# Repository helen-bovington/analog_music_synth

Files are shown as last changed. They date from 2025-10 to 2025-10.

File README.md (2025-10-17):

# EE Senior Capstone - Surface Electromyogram-Controlled (sEMG) Analog Audio Synthesizer
## Capstone Members - Helen Bovington, Anya Trumbach, Daryl Choo, Kayla Montgomery
## Date Completed : 15 May 2025 

HOW TO RUN THIS CODE

Hardware
- To simulate the hardware circuit, install Cadence Virtuoso. This program allows transistor-level schematic simulation.
- Download the entire folder of Cadence files included in this repository, create a new library in Virtuoso, and use ADE L to execute the simulations.
- Both the fully integrated circuit and individual blocks can be simulated independently.

Software
- To simulate the software, you will need at least three ESP32 chips, one server and two clients.
- Upload the corresponding client and server code to each chip, and follow the directions in the technical documentation.
- Note that fully reproducing the system may be challenging, as it requires integrating both the EMG and 9DOF sensors, and successfully implementing the communication protocol in all the ESP32 chips.

DESCRIPTION OF EACH FILE/FOLDER: 

Cadence_files 

- Contains all Cadence schematic files for download, simulation, or modification. Includes the spiceText and symbol files required to run the analog synthesizer circuits successfully.

PCB_documents

- Contains all the PCB schematic (.SchDoc) and layout (.PcbDoc) files for the analog synthesizer blocks, including CEM3340 VCO, Gilbert Mixer, LIN-EXPO Converter, VCA, MUX, Sustain, and Waveform Reshaper circuits.

schematics_and_waveforms

- Contains screenshots of all the Cadence schematics and resulting simulated waveforms for the analog synthesizer blocks.

video_demos

- [Watch the pitch_volume_demo](https://drive.google.com/file/d/1nATk0rh68sWONzXLJCf0UebWwm36ZEd-/view?usp=drive_link)
- [Watch the waveform_demo](https://drive.google.com/file/d/1uY7D6FP98FlUV1h7C2OQBhmS08Et43su/view?usp=sharing)

analog_synth_block_diagram.png

- A high-level, but complete and accurate, block diagram showing how the various blocks of the analog synthesizer are connected.

analog_synth_poster.pdf

- A project poster summarizing the design, implementation, and results of the analog synthesizer capstone project.

system_block_diagram.png

- A block diagram showing the whole system integration including the 9DOF and sEMG sensors, ESP32 chips, communication protocol, analog circuit, and power amp leading to the speaker.

technical_report.pdf

- A document which organizes and details all aspect of the project. It includes all the communication and ML code, decription of the movement library, detailed descriptions of the analog blocks, and short overview of the PCB fabrication process.

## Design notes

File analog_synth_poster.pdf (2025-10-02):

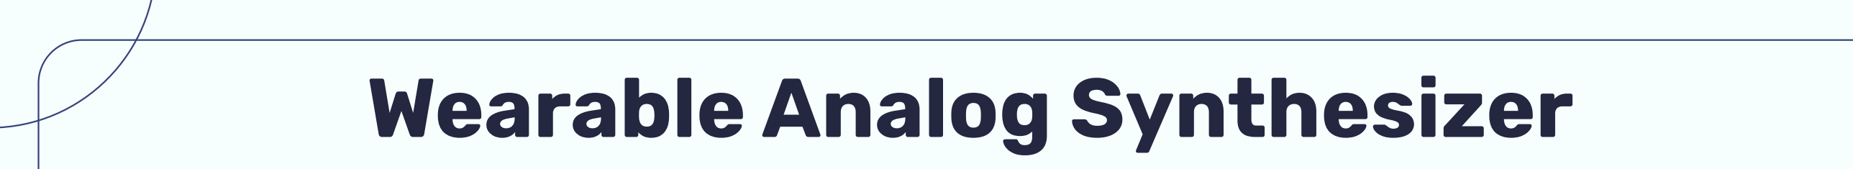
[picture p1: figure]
Wearable Analog Synthesizer

Advisors: Professor David G. Vallencourt, Electrical Engineering, Professor Seth Cluett, Computer Music Center

# Helen Bovington, Daryl Choo, Anya Trumbach, Kayla Montgomery

# Abstract

The synthesizer is a wearable sleeve equipped with MyoWare 2.0 sensors that detect muscle activity from the forearm and upper arm. A 9-degree-of-freedom (9DOF) sensor provides real-time tracking of arm orientation using accelerometer data (x, y, z axes). Sensor data is wirelessly transmitted via ESP32 microcontrollers mounted on custom PCBs. The output of the server ESP generates CVs that interact with a modular analog circuit responsible for generating and modifying audio waveforms. Users can select different waveform types because of MUXes integrated in the analog circuit. Users can control frequency and amplitude by raising their forearm, as the acceleration data is mapped to control voltages. More details about the circuitry components can be found in its block diagram below. The output of the analog circuitry is wired to a speaker.

# Hardware Description

# Analog Block Diagram

Arm

The software side handles data acquisition, wireless transmission, and gesture recognition. Using C++ based code developed in Visual Studio Code with the PlatformIO extension, ESP32 microcontrollers collect real-time signals from EMG sensors and a 9DOF sensor (accelerometer only). These signals are transmitted over Bluetooth to a server ESP. A machine learning model is trained on this data to associate specific combinations of muscle activity and arm movement with predefined hand gestures. Once trained, the model classifies incoming data in real time and outputs corresponding control signals. These signals determine waveform selection, pitch, and amplitude within the analog synthesizer circuit. A calibration script ensures reliable performance across different users and usage sessions.

# List of Movements: A “How-To” Use Guide

The surface electromyogram (sEMG)-controlled audio synthesizer are wearable sleeves that make real time effects on sound output through selected arm movements and hand gestures, as outlined in the “List of Movements” section. The sleeve allows users to select different waveforms, control amplitude and frequency, and add a sustaining effect to the audio, creating a vibrato effect. Together, these features make the device a flexible, non-restrictive musical instrument.
To achieve this functionality, we used two sEMG sensors and accelerometer (xyz-axis) data from a 9DOF sensor placed on key forearm and upper arm muscles (see images A & B) to collect training data. This data was used to train a machine learning model that maps muscle activity to specific selector commands. Inside the sleeve is an ESP32 chip paired with a calibration system used to normalize amplitude output of muscle movements, making the system flexible to different users. The sensors interface with ESP32 chips, which transmit data wirelessly via Bluetooth Light. The server ESP32 chip directly feeds the control voltages to the analog circuit, allowing the user to modify the waveform in real time. More details on the analog circuit are provided in the Hardware section.

# Software Description

# General Block Diagram

# Supporting Images

# Device

## Gilbert Mixer

A) Flexor Digitorum | B) Extensor carpi radialis
Profundus - The inner muscle group of arm. Palms facing down. | valgus longus - The outer muscle group of the arm. Palm facing down.
C) Velcro based for an all-size fit. Inside of the sleeve is the accelerometer, a calibration button (with LED indication), an ESP32 chip, an EMG sensor that will make contact with the user’s skin and a three different batteries of various voltages to power the sleeve.

Left Arm - Hand & Forearm
Orientation

Right Arm - Hand & Forearm Orientation

Hand or
Arm
Movement

Amplitude (volume) → Raise motion: Hold your arm at a 90 degree angle with your palm facing up. Bend your elbow and raise your forearm up until your forearm is perpendicular to the ground.

Waveform setting: Sawtooth wave → Extend motion: Hold your arm at a 90 degree angle with your palm facing up. Bend your wrist backwards until your palm is facing away from you.

Pitch → Raise motion: Hold your arm at a 90 degree angle with your palm facing up. your forearm is perpendicular to the ground.

Hand

Waveform setting: AM Modulation (Hilbert Mixer) → Extend motion: Hold your arm at a 90 degree angle with your palm facing up. Bend your wrist backwards until your palm is facing away from you.

Waveform setting: Sine Wave → Fist motion: Close your hand into a fist. Keep your arm forearm facing the ceiling. | Sustain (vibrato effect): Fist Motion: Close your hand into a fist. Keep your forearm facing the ceiling.
Waveform setting: Triangle wave → Flex Motion: Hold your arm at a 90 degree angle with your palm facing up. Use your wrist to raise your hand until your palm is upright, facing your face. | | Analog Waveforms

Hand

Hand

*Note: Any arm movement corresponds to the accelerometer from the 9DOF sensor, any hand movement corresponds to the EMG sensor.

VCA | Waveform Reshaper

Linear -> Expo Converter

Waveform Selector | Sustain

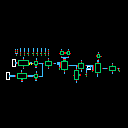
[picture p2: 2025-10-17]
Cadence_files/TEST/schematic/thumbnail_128x128.png

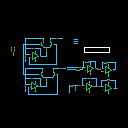
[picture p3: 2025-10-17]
Cadence_files/LIN_EXPO/schematic/thumbnail_128x128.png

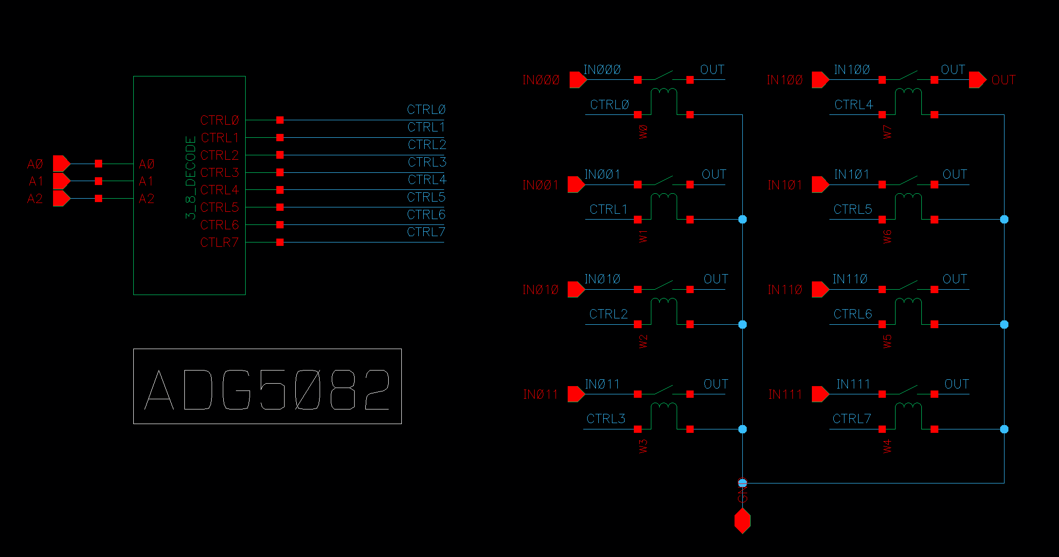
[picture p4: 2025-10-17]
schematics_and_waveforms/ADG5082_Sch.png

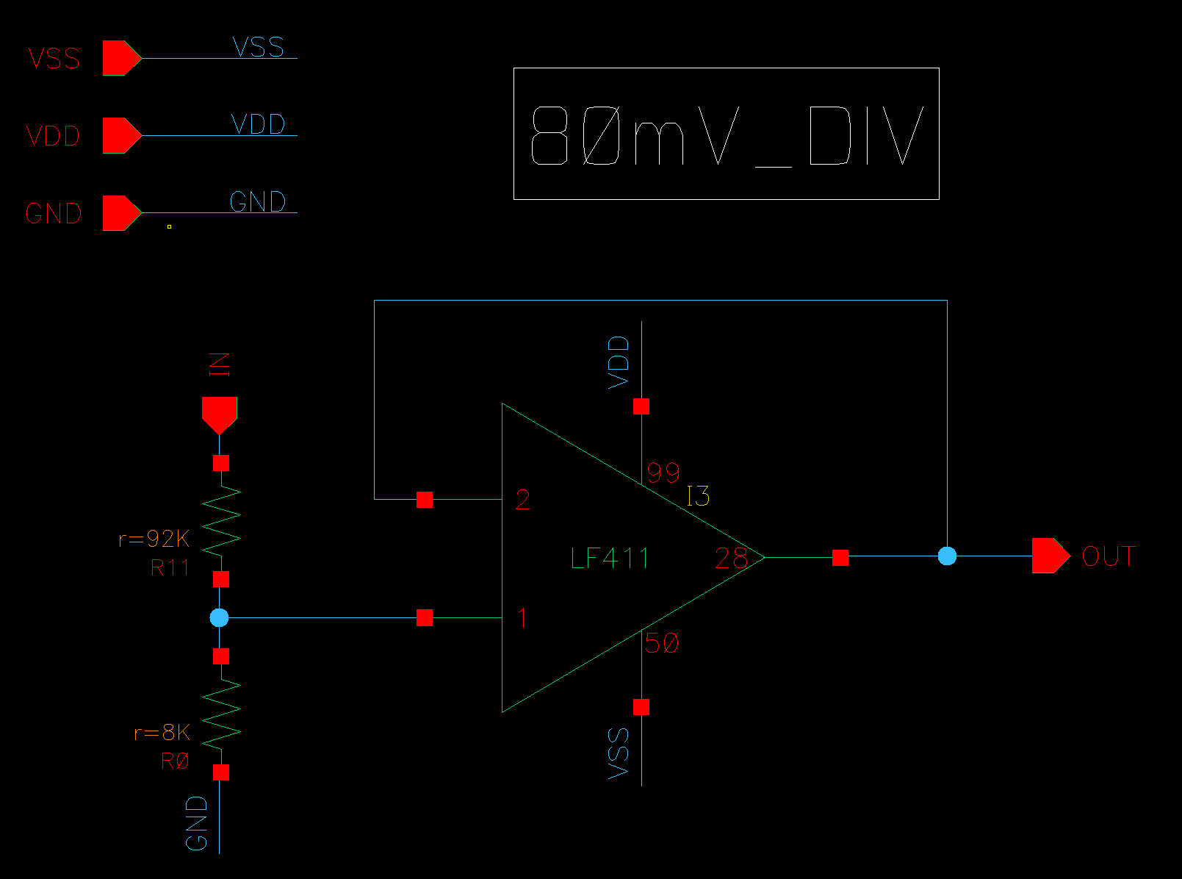
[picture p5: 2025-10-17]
schematics_and_waveforms/80mV_DIV_Sch.png

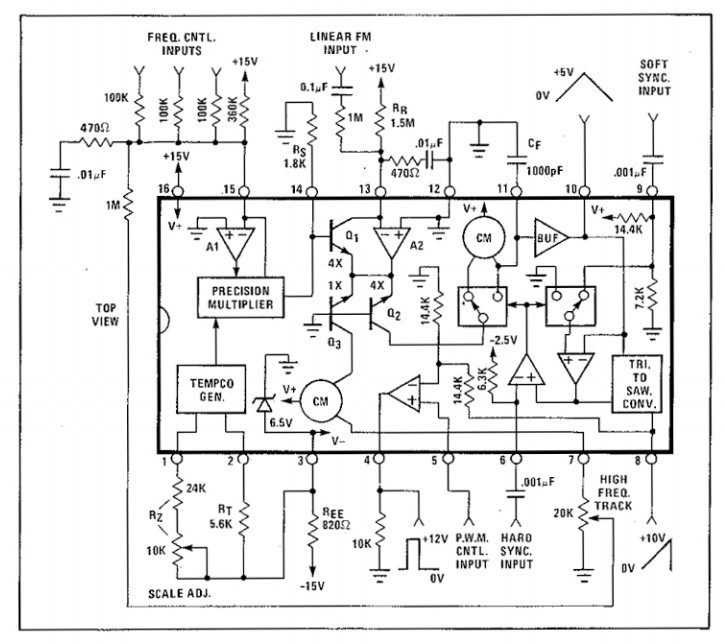
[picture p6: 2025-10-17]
schematics_and_waveforms/CEM3340_Sch.png

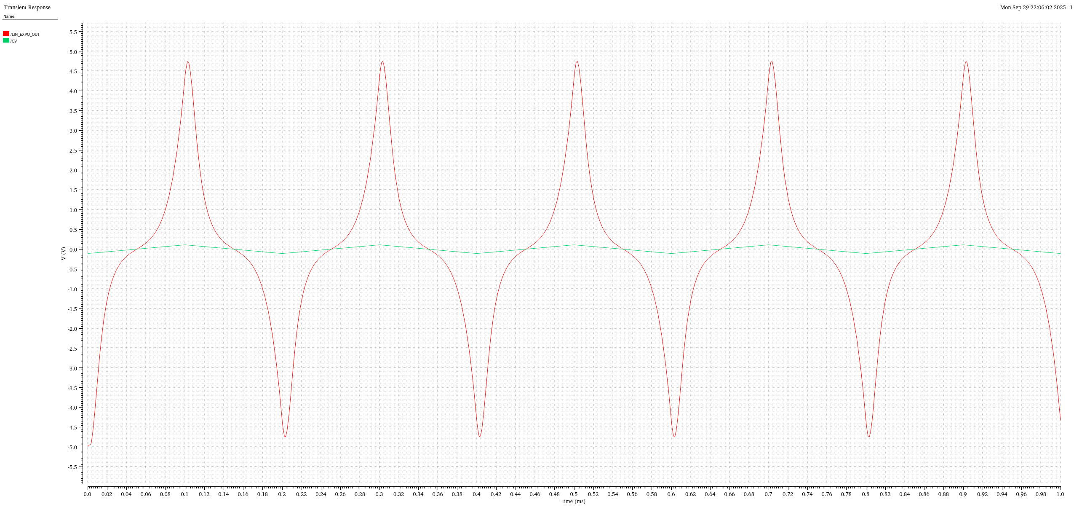
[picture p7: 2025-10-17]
schematics_and_waveforms/LIN_EXPO_CONVERTER_waveform.png

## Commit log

2025-10-02 add finalized folder with PCB schematics and layout
    [CEM3340.PcbDoc, CEM3340.SchDoc, GILBERT.PcbDoc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]
2025-10-17 adding Cadence_files and schematics_and_waveforms folders
